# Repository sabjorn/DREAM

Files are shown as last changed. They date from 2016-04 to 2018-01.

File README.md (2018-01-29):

## D.R.E.A.M - *D*ata *R*ules *E*verything *A*round *M*e

## About
*dreamIO* is an ESP8266 based development board for designing interactive art applications. 

The board features MPU-6050 6-Axis IMU, TPS61200 Voltage Regulator, MCP73831 Lipo Charger, and 12x WS2812B RGB LEDs. 

The functionality of the board is made available through an OSC based API. Through this network interface, large, complex, and distributed interactive applications can be developed with little (to no) microcontroller programming. Instead, designers can use any language of their choice (any languague which supports UDP messaging) and any platform of their choice (Mac, Windows, Linux) to write the software which communicates with these devices. 

## Development Status
Early development stages, version 0.~

**Note**: The current PCB design in the git is broken from an attempt to fix 

### Arduino SDK info
Currently only version **2.0.0** of ESP8266 for Arduino is supported for this project. 

## External Libraries
* [ESP8266 Arduino](https://github.com/esp8266/Arduino) - 2.0.0
* [I2CDev](https://github.com/jrowberg/i2cdevlib) for the MPU-6050
* [OSC](https://github.com/CNMAT/OSC) 
* [Adafruit NeoPixels](https://github.com/adafruit/Adafruit_NeoPixel) - 1.0.6 **Use the Arduino Package Manager version**

## Future
The addition of a haptics motor is likely.

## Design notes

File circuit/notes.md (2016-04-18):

All resistors are size `SMD 0603`. They have a maximum dissipation of .1W and none of the resistors will get near this.

based on: http://electronics.stackexchange.com/questions/12409/choosing-surface-mount-resistor-capacitors

The battery is 5cm x 3cm

PCB will (currently) be 6x6mm, 5mm will not work, there is simply not enough space?

#### [Seeed Studio Design Rules](http://support.seeedstudio.com/knowledgebase/articles/422482-fusion-pcb-order-submission-guidelines)

| Item | Specs | |
|---|---|---|
| | Unit: mm | Unit: mil |
| Available Board Thickness | 0.4(4 layer except),0.6, 0.8, 1.0, 1.2, 1.6, 2.0 | 15.7(4 layer except), 23.6, 31.5, 39.4, 47.2, 63.0, 78.7 |
| Board Dimension | min size: 20*20Max size:300*300 | —— |
| Board Thickness Tolerance | ± 10% | ± 10% |
| Dielectric Separation thickness | 0.075 - 5.0 | 2.95 - 196.85 |
| Minimum trace width | 0.1524 | 6 |
| Minimum inner trace width (for 4 layer) | 0.204 | 8 |
| Minimum trace/vias/pads space | 0.1524 | 6 |
| Minimum inner trace/vias/pads space (for 4 layer) | 0.254 | 10 |
| Minimum silkscreen width | 0.1524 | 6 |
| Minimum silkscreen text size | 1 | 40 |
| Minimum distance between pads and silkscreen | 0.178 | 7 |
| Out Layer Copper Thickness (4 layers) | 0.035-0.07(1oz-2oz) | 1.38-2.76 |
| Inner Layer Copper Thickness (4 layers) | 0.017(0.5oz) | 0.67 |
| Drilling Hole Diameter (Mechanical) | 0.3 - 6.35 | 11.81 - 250.00 |
| Annular Ring | ≥0.1524 | ≥6 |
| Diameter Tolerance (Mechanical) | ±0.08 | ± 3.148 |
| SMT min Solder Mask Width | 0.1 | 3.94 |
| Min Solder Mask Clearance | 0.13 | 5.12 |
| Circuit to edge | ≥0.4 | ≥15.76 |
| Mimimum distance between inner line/copper and drilling hole | ≥0.3 | ≥11.82 |
| Minimum milling slot | 1*2 | 39.385*78.77 |
| Slot Tolerance(Mechanical) | ±0.15mm | |
| The minimum board dimension of V-CUT | 80mm*80mm | |
| Aspect Ratio | 08:01:00 | |
| Solder Mask Type | Photosensitive ink | |

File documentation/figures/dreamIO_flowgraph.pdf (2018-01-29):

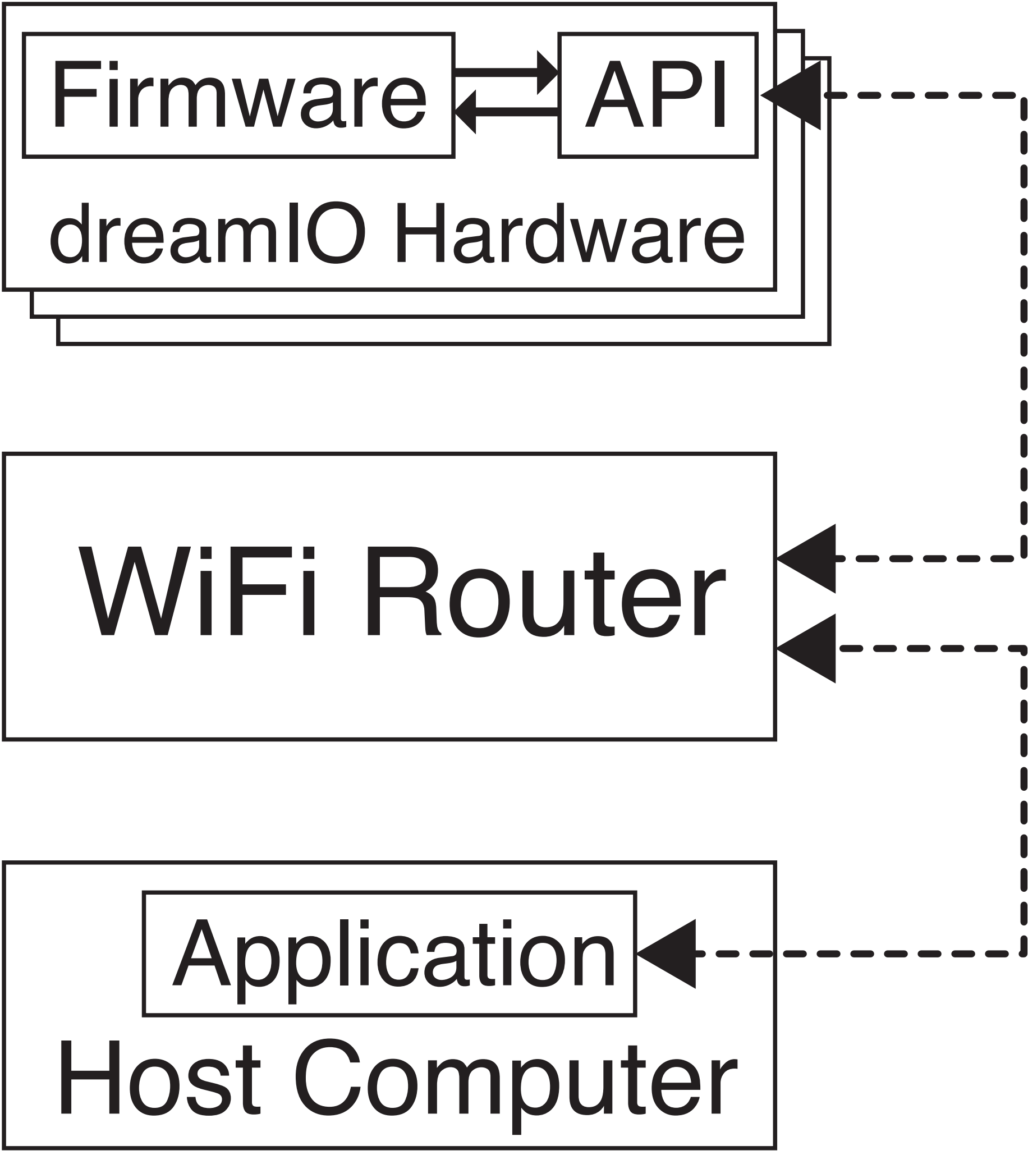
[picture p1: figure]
Application Host Computer; WiFi Router; Firmware; API; dreamIO Hardware

OSC OSC

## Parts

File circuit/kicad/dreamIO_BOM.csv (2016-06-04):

Id | Designator | Package | Quantity | Designation | Supplier and ref
1 | C1,C2 | 0603 | 2 | 4.7uF
2 | C3,C13 | 0603 | 2 | 10uF
3 | C5 | 0603 | 1 | 22uF
4 | C6,C9,C10,C11,C12,C14,C15,C16,C17,C18,C19,C20,C21,C22,C24,C25 | 0603 | 16 | 0.1uF
5 | C23 | 0603 | 1 | 0.01uF
6 | C26 | 0603 | 1 | 2200pF
7 | IC1 | tps61200_QFN-10_PAD | 1 | TPS61200
8 | L1 | 1206E | 1 | 2.2uH, 1.2A
9 | LED1,LED2,LED3,LED4,LED5,LED6,LED7,LED8,LED9,LED10,LED11,LED12 | WS2812B_LED | 12 | WS2812B
10 | P1 | Pin_Header_Straight_1x02 | 1 | BATT
11 | P9 | Pin_Header_Straight_1x03 | 1 | PixelOut
12 | R1 | 0603 | 1 | 330
13 | R2 | 0603 | 1 | 2.0k
14 | R3,R5 | 0603 | 2 | 2M
15 | R4 | 0603 | 1 | 1.2M
16 | R6,R7 | 0603 | 2 | 220k
17 | R8,R9,R10,R11,R16,R13,R14 | 0603 | 7 | 10k
18 | R12 | 0603 | 1 | 220
19 | R25,R26,R27 | 0603 | 3 | 4.7k
20 | U1 | SOT23-5 | 1 | MCP73831
21 | U2 | MICRO-B_USB | 1 | MICRO-B_USB
22 | U4 | ESP-12E | 1 | ESP-12E
23 | D1 | 0603 | 1 | LED
24 | P2,P3 | _Pin2mm_8 | 2 | CONN_01X08
25 | P5 | _Pin2mm_6 | 1 | CONN_01X06
26 | P4 | _Solder_Pad2.54_2 | 1 | CONN_01X02
27 | SW2 | SW_06_SMD | 1 | RESET
28 | SW3 | SW_06_SMD | 1 | PRGM
29 | H4,H4,H4,H4 | 1pin | 4 | SCREWHOLE
30 | SW1 | DPST_TE_SSJ12R04 | 1 | SPDT
31 | SW4 | SW_06_SMD | 1 | HCI2
32 | SW5 | SW_06_SMD | 1 | HCI1
33 | U17 | QFN-24-4x4-EP_steevedit | 1 | MPU-6050
34 | R15 | 0603 | 1 | 330K

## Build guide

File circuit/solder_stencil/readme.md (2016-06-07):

these files are for creating a solder-paste stencil
using a laser cutter an mylar.

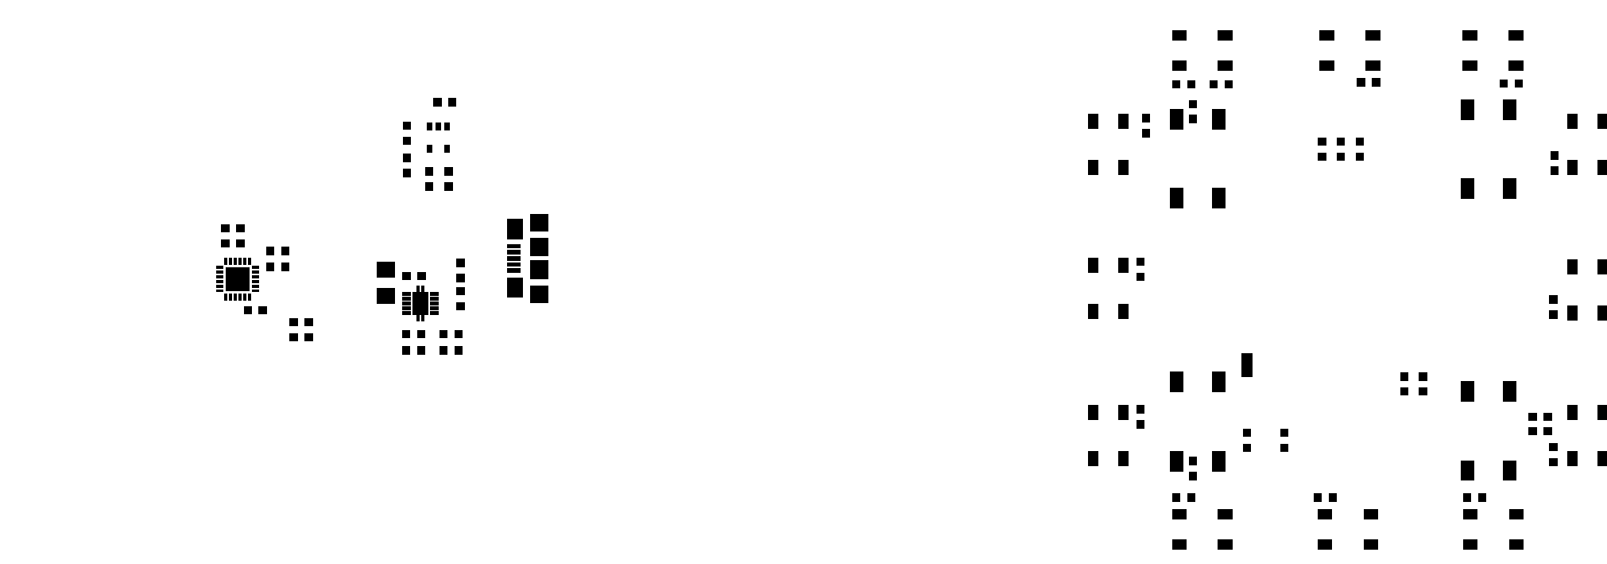
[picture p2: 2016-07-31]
circuit/solder_stencil/stencil_noholes.BMP

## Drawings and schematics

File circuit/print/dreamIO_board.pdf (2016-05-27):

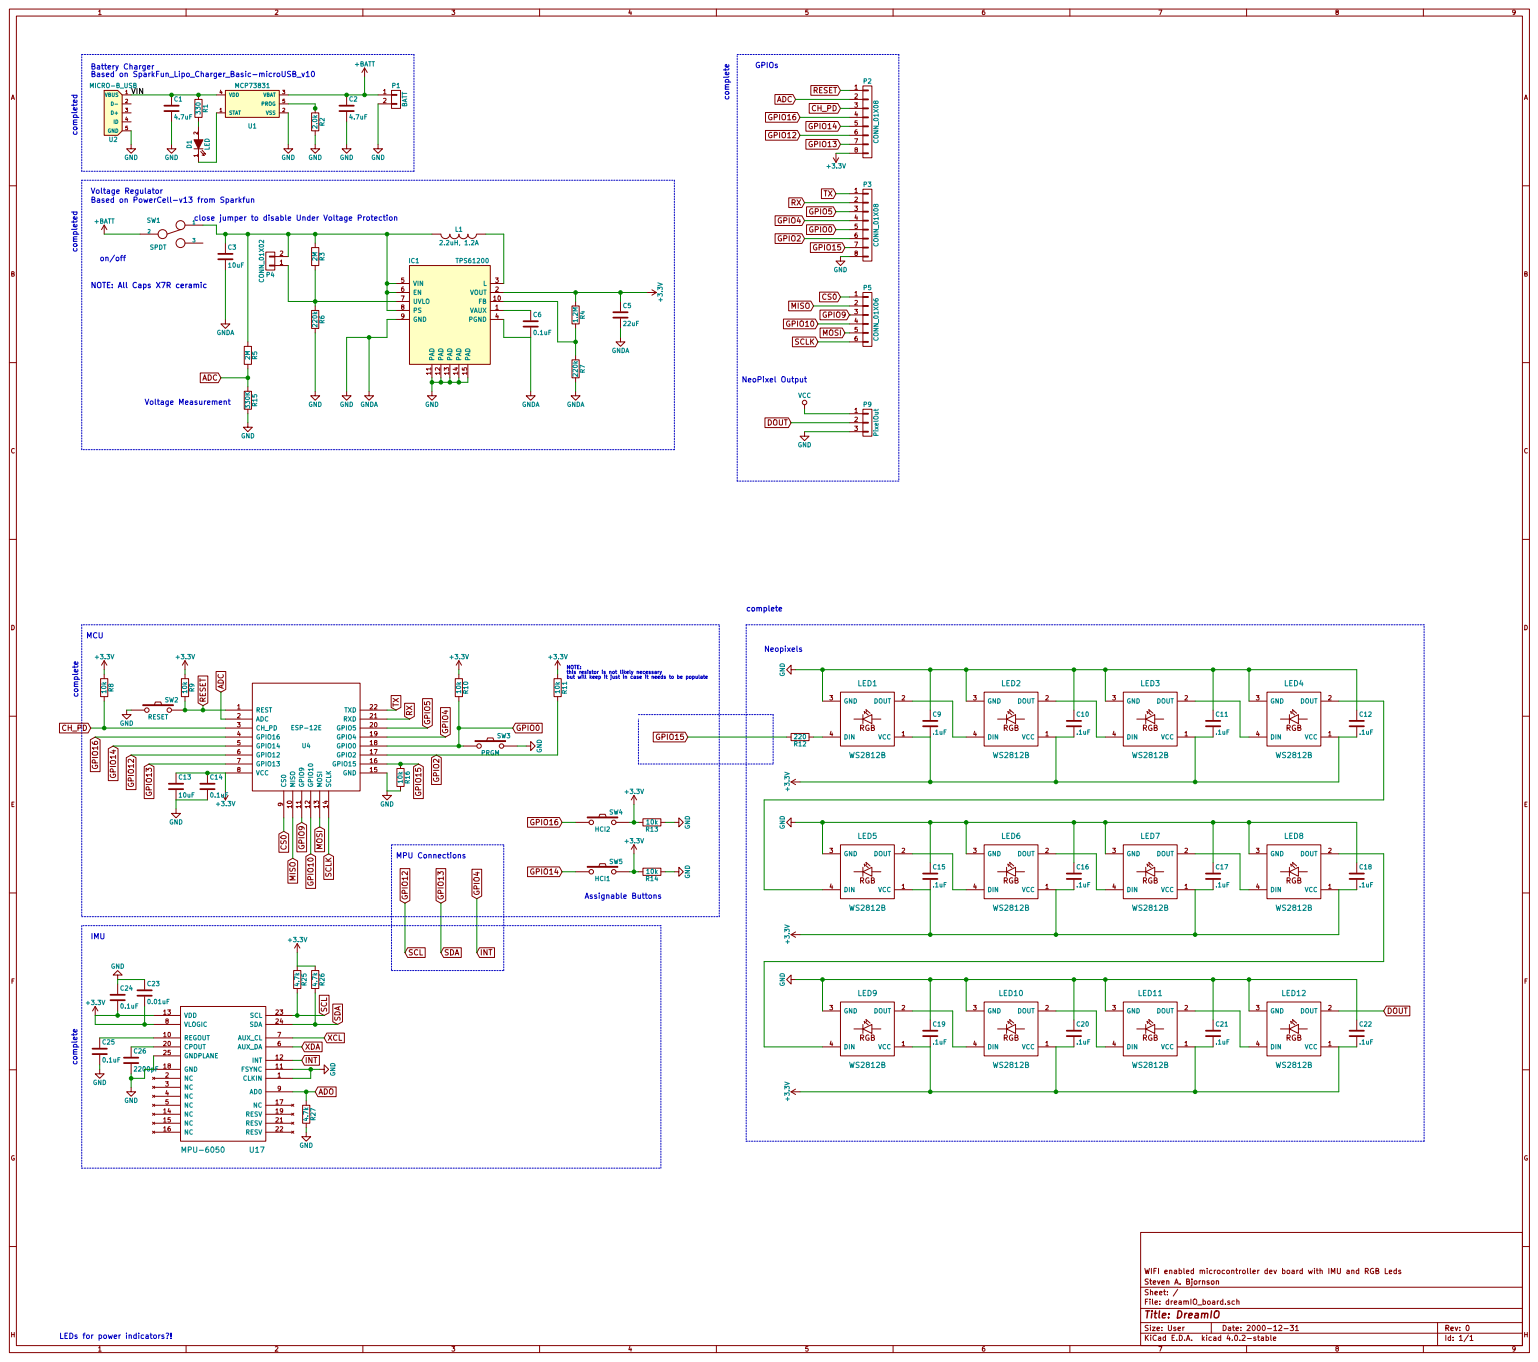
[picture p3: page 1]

1 2 D1 LED Battery Charger Based on SparkFun_Lipo_Charger_Basic-microUSB_v10

close jumper to disable Under Voltage Protection Based on PowerCell-v13 from Sparkfun Voltage Regulator on/off completed completed

this resistor is not likely necessary but will keep it just in case it needs to be populate GPIO13 GPIO12 GPIO14 GPIO16 MCU

9 MISO 10 GPIO5 20 GPIO9 11 RXD 21 GPIO10 12 TXD 22 MOSI 13 SCLK 14 GND 15 GPIO15 16 GPIO2 17 GPIO0 18 GPIO4 19 U4 ESP-12E complete

File: dreamIO_board.sch Sheet: / Steven A. Bjornson WIFI enabled microcontroller dev board with IMU and RGB Leds

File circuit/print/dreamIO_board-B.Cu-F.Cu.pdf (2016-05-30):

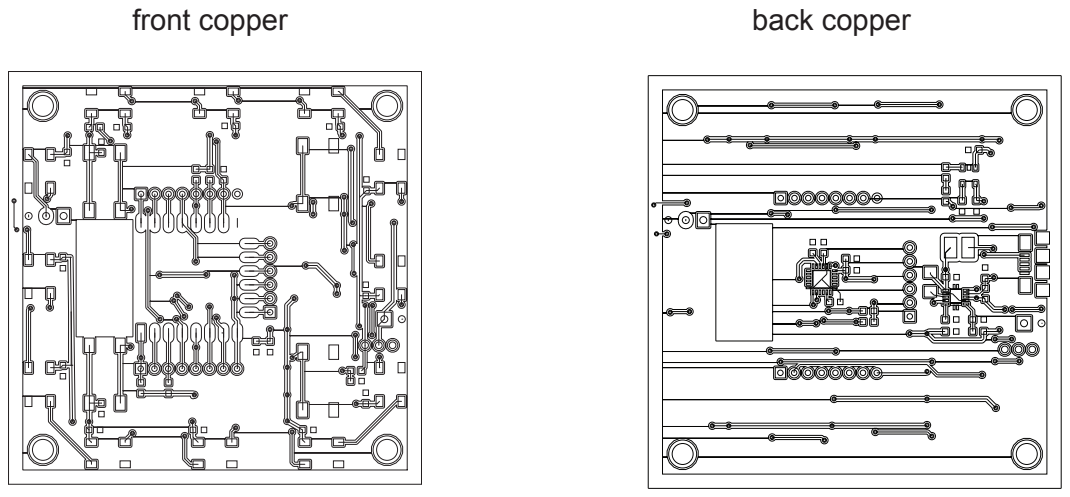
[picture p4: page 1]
front copper; back copper

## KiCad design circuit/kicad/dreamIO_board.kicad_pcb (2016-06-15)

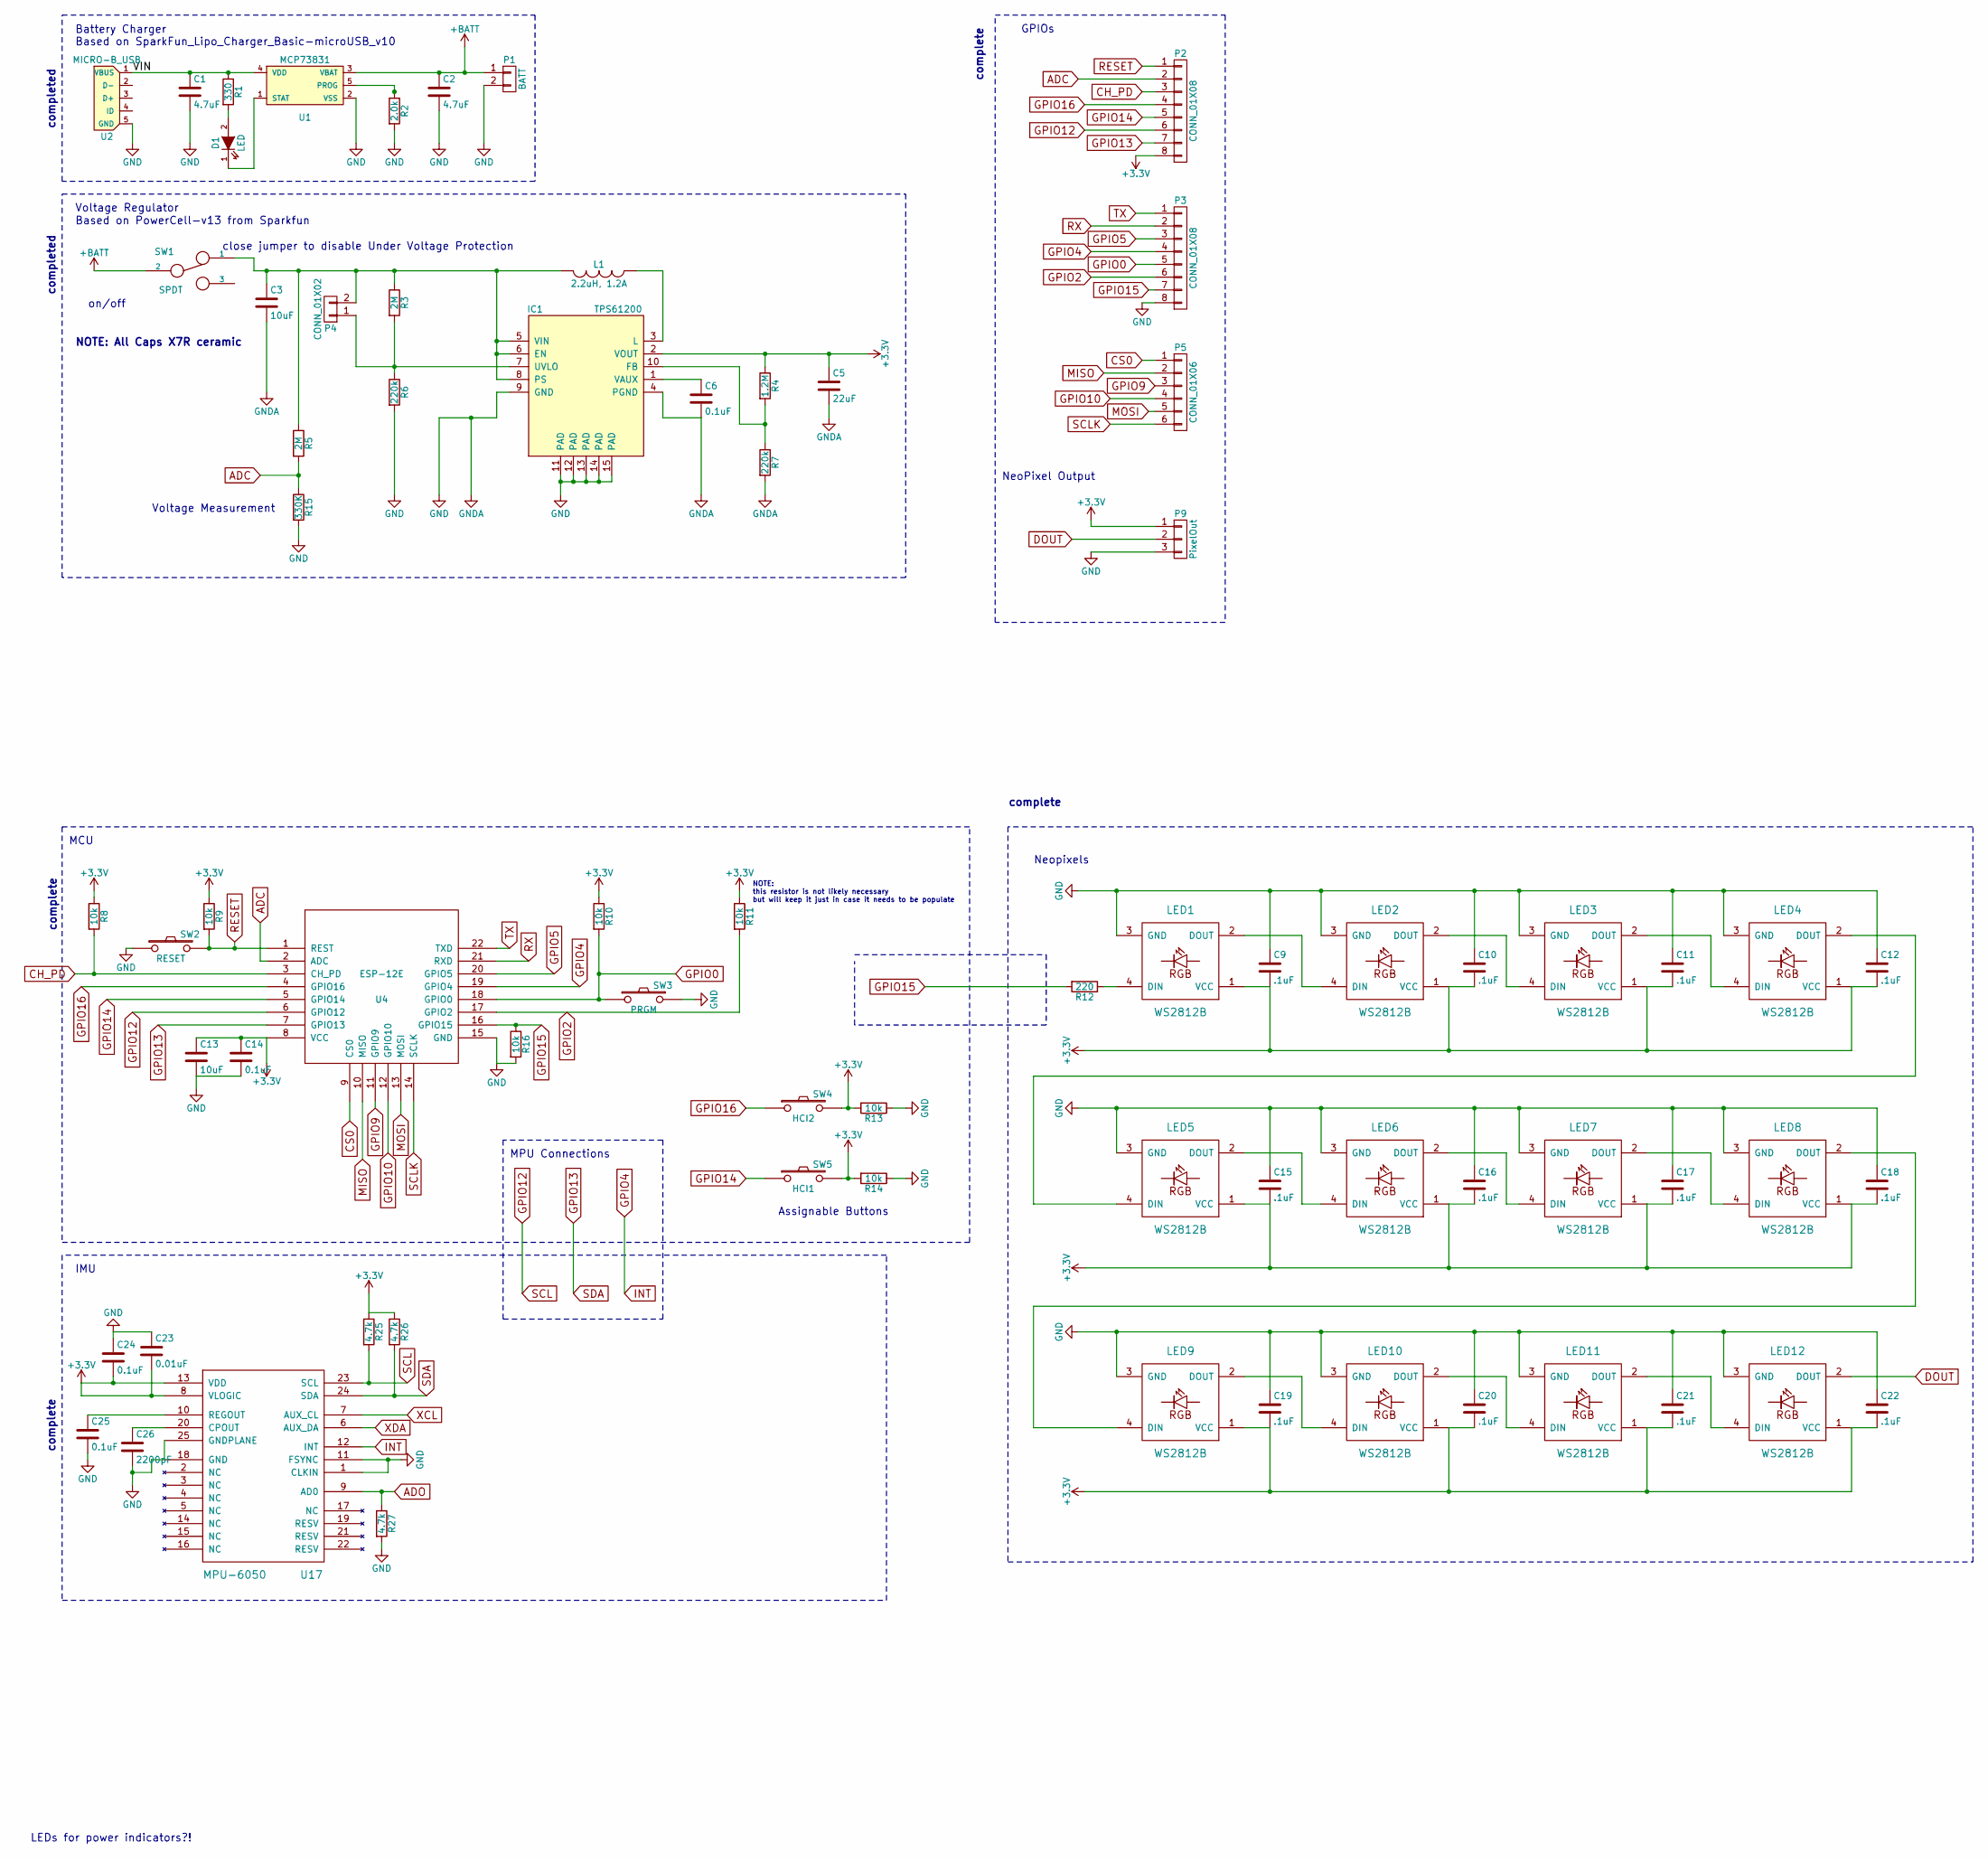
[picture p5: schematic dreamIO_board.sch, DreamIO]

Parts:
C1, C2: 4.7uF; 0603
C3, C13: 10uF; 0603
C5: 22uF; 0603
C6, C14, C24, C25: 0.1uF; 0603
C9, C10, C11, C12, C15, C16, C17, C18, C19, C20, C21, C22: .1uF; 0603
C23: 0.01uF; 0603
C26: 2200pF; 0603
D1: LED; 0603
IC1: TPS61200; tps61200_QFN-10_PAD
L1: 2.2uH, 1.2A; 1206E
LED1, LED2, LED3, LED4, LED5, LED6, LED7, LED8, LED9, LED10, LED11, LED12: WS2812B; WS2812B_LED
P1: BATT; Pin_Header_Straight_1x02
P2, P3: CONN_01X08; _Pin2mm_8
P4: CONN_01X02; _Solder_Pad2.54_2
P5: CONN_01X06; _Pin2mm_6
P9: PixelOut; PIN_ARRAY_3X1
R1: 330; 0603
R2: 2.0k; 0603
R3, R5: 2M; 0603
R4: 1.2M; 0603
R6, R7: 220k; 0603
R8, R9, R10, R11, R13, R14, R16: 10k; 0603
R12: 220; 0603
R15: 330K; 0603
R25, R26, R27: 4.7k; 0603
SW1: SPDT; DPST_TE_SSJ12R04
SW2: RESET; SW_06_SMD
SW3: PRGM; SW_06_SMD
SW4: HCI2; SW_06_SMD
SW5: HCI1; SW_06_SMD
U1: MCP73831; SOT23-5
U2: MICRO-B_USB
U4: ESP-12E
U17: MPU-6050; QFN-24-4x4-EP_steevedit

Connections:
+3V3: C5.1, C9.2, C10.2, C11.2, C12.2, C13.1, C14.1, C15.2, C16.2, C17.2, C18.2, C19.2, C20.2, C21.2, C22.2, C23.2, C24.2, IC1.2 (VOUT), LED1.1 (VCC), LED2.1 (VCC), LED3.1 (VCC), LED4.1 (VCC), LED5.1 (VCC), LED6.1 (VCC), LED7.1 (VCC), LED8.1 (VCC), LED9.1 (VCC), LED10.1 (VCC), LED11.1 (VCC), LED12.1 (VCC), P2.8, P9.1, R4.1, R8.1, R9.1, R10.1, R11.1, R13.2, R14.2, R25.1, R26.1, SW4.2, SW5.2, U4.8 (VCC), U17.8 (VLOGIC), U17.13 (VDD)
+BATT: C2.1, P1.1, SW1.2, U1.3 (VBAT)
/VIN: C1.1, R1.1, U1.4 (VDD), U2.1 (VBUS)
ADC: P2.2, R5.2, R15.1, U4.2 (ADC)
ADO: R27.1, U17.9 (AD0)
CH_PD: P2.3, R8.2, U4.3 (CH_PD)
CS0: P5.1, U4.9 (CS0)
DOUT: LED12.2 (DOUT), P9.2
GND: C1.2, C2.2, C3.2, C5.2, C6.2, C9.1, C10.1, C11.1, C12.1, C13.2, C14.2, C15.1, C16.1, C17.1, C18.1, C19.1, C20.1, C21.1, C22.1, C23.1, C24.1, C25.2, C26.2, IC1.4 (PGND), IC1.9 (GND), IC1.11 (PAD), IC1.12 (PAD), IC1.13 (PAD), IC1.14 (PAD), IC1.15 (PAD), LED1.3 (GND), LED2.3 (GND), LED3.3 (GND), LED4.3 (GND), LED5.3 (GND), LED6.3 (GND), LED7.3 (GND), LED8.3 (GND), LED9.3 (GND), LED10.3 (GND), LED11.3 (GND), LED12.3 (GND), P1.2, P3.8, P9.3, R2.2, R6.2, R7.2, R13.1, R14.1, R15.2, R16.2, R27.2, SW2.1, SW3.2, U1.2 (VSS), U2.5 (GND), U4.15 (GND), U17.1 (CLKIN), U17.11 (FSYNC), U17.18 (GND), U17.25 (GNDPLANE)
GPIO0: P3.5, R10.2, SW3.1, U4.18 (GPIO0)
GPIO2: P3.6, R11.2, U4.17 (GPIO2)
GPIO4: P3.4, U4.19 (GPIO4), U17.12 (INT)
GPIO5: P3.3, U4.20 (GPIO5)
GPIO9: P5.3, U4.11 (GPIO9)
GPIO10: P5.4, U4.12 (GPIO10)
GPIO12: P2.6, R25.2, U4.6 (GPIO12), U17.23 (SCL)
GPIO13: P2.7, R26.2, U4.7 (GPIO13), U17.24 (SDA)
GPIO14: P2.5, SW5.1, U4.5 (GPIO14)
GPIO15: P3.7, R12.2, R16.1, U4.16 (GPIO15)
GPIO16: P2.4, SW4.1, U4.4 (GPIO16)
MISO: P5.2, U4.10 (MISO)
MOSI: P5.5, U4.13 (MOSI)
unnamed: C3.1, IC1.5 (VIN), IC1.6 (EN), IC1.8 (PS), L1.2, P4.2, R3.1, R5.1, SW1.1
unnamed: C6.1, IC1.1 (VAUX)
unnamed: C25.1, U17.10 (REGOUT)
unnamed: C26.1, U17.20 (CPOUT)
unnamed: D1.1 (K), U1.1 (STAT)
unnamed: D1.2 (A), R1.2
unnamed: IC1.3 (L), L1.1
unnamed: IC1.7 (UVLO), P4.1, R3.2, R6.1
unnamed: IC1.10 (FB), R4.2, R7.1
unnamed: LED1.2 (DOUT), LED2.4 (DIN)
unnamed: LED1.4 (DIN), R12.1
unnamed: LED2.2 (DOUT), LED3.4 (DIN)
unnamed: LED3.2 (DOUT), LED4.4 (DIN)
unnamed: LED4.2 (DOUT), LED5.4 (DIN)
unnamed: LED5.2 (DOUT), LED6.4 (DIN)
unnamed: LED6.2 (DOUT), LED7.4 (DIN)
unnamed: LED7.2 (DOUT), LED8.4 (DIN)
unnamed: LED8.2 (DOUT), LED9.4 (DIN)
unnamed: LED10.2 (DOUT), LED11.4 (DIN)
unnamed: LED9.2 (DOUT), LED10.4 (DIN)
unnamed: LED11.2 (DOUT), LED12.4 (DIN)
unnamed: R2.1, U1.5 (PROG)
RESET: P2.1, R9.2, SW2.2, U4.1 (REST)
RX: P3.2, U4.21 (RXD)
SCLK: P5.6, U4.14 (SCLK)
TX: P3.1, U4.22 (TXD)

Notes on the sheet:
Battery Charger Based on SparkFun_Lipo_Charger_Basic-microUSB_v10
close jumper to disable Under Voltage Protection
Based on PowerCell-v13 from Sparkfun
Voltage Regulator
on/off
completed
NOTE: All Caps X7R ceramic
Neopixels
IMU
complete
NOTE: this resistor is not likely necessary but will keep it just in case it needs to be populate
MCU
GPIOs
LEDs for power indicators?!
MPU Connections
NeoPixel Output
Assignable Buttons
Voltage Measurement

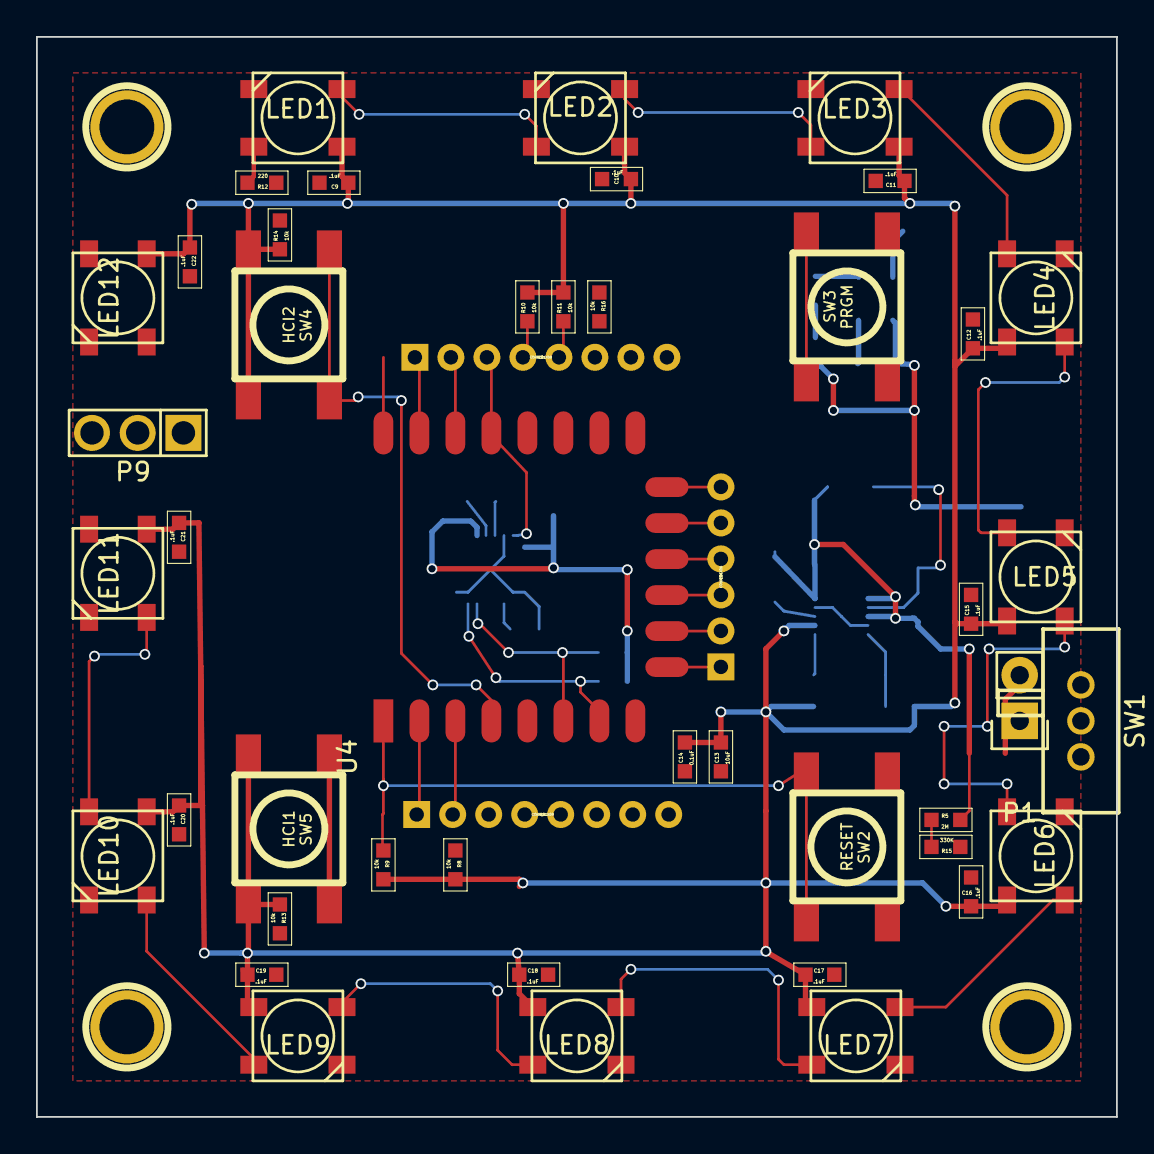
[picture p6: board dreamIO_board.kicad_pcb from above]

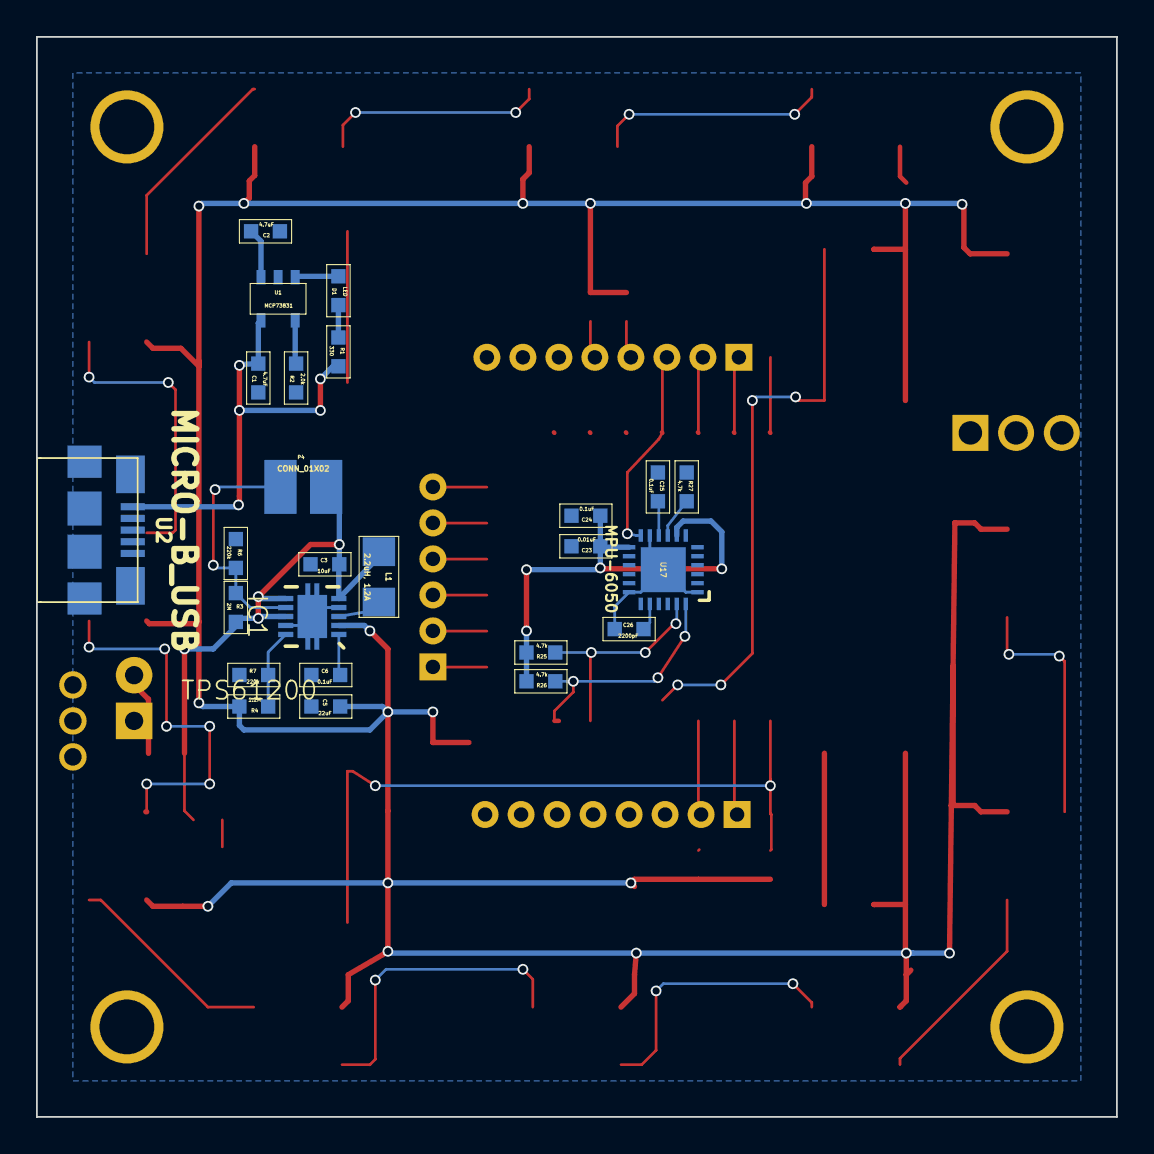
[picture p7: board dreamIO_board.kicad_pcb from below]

Board: 2 copper layers, 60.0 x 60.0 mm, 76 parts (25 on the bottom side), 48 nets.

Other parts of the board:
H4, H4#2, H4#3, H4#4: SCREWHOLE; 1pin

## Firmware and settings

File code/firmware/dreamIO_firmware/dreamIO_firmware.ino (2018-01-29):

/*Example code for OSC message send/recieve with ESP8266
Based on example code made available through CNMAT
Written by: Steven A. Bjornson | 19/12/15

Included is a Max/MSP patch for controlling a single LED on board.
Max patch uses CNMAT OSC externals*/
#include <ESP8266WiFi.h>
#include <ESP8266WiFiMulti.h>
// #include <WiFiClient.h>
// #include <WiFiClientSecure.h>
#include <WiFiServer.h>
#include <WiFiUdp.h>
#include <ESP8266mDNS.h>
#include <ArduinoOTA.h>

#include <OSCMessage.h>
#include <OSCBundle.h>

#include <Adafruit_NeoPixel.h>
#include "wifiCred.h" //used to store SSID and PASS

#include <Math.h>
#include <cstdint>

#include "MotionState.h"
#include "ImuDataContainer.h"

/*Voltage Measurement*/
// Voltage divider on ADC allows for a measurement of battery voltage.
// maybe these don't need to be preprocessor
#define V_RES float(1./256.) //the number of volts per step
#define R1 float(200.)
#define R2 float(33.)
#define V_SCALE float(R2 / (R1 + R2))
#define V_MIN float(2.6) //the undervoltage shutoff of voltage regulator
#define V_MAX float(4.2) //the theoretical maximum voltage of LiPo
#define SCALED_V_MIN float(V_SCALE * V_MIN / V_RES)
#define SCALED_V_MAX float(V_SCALE * V_MAX / V_RES)

#define abs(x) ((x)>0?(x):-(x)) //taken from STD

/*MPU*/
#include "I2Cdev.h"
#include "MPU6050_6Axis_MotionApps20.h"

#if I2CDEV_IMPLEMENTATION == I2CDEV_ARDUINO_WIRE
    #include "Wire.h"
#endif

MPU6050 mpu;

// MPU control/status vars
bool dmpReady = false;  // set true if DMP init was successful
uint8_t mpuIntStatus;   // holds actual interrupt status byte from MPU
uint8_t devStatus;      // return status after each device operation (0 = success, !0 = error)
uint16_t packetSize;    // expected DMP packet size (default is 42 bytes)
uint16_t fifoCount;     // count of all bytes currently in FIFO
uint8_t fifoBuffer[64]; // FIFO storage buffer

// orientation/motion vars
Quaternion q;           // [w, x, y, z]         quaternion container
VectorInt16 aa;         // [x, y, z]            accel sensor measurements
VectorInt16 aaReal;     // [x, y, z]            gravity-free accel sensor measurements
VectorInt16 aaWorld;    // [x, y, z]            world-frame accel sensor measurements
VectorFloat gravity;    // [x, y, z]            gravity vector
VectorInt16 gyro;
float euler[3];         // [psi, theta, phi]    Euler angle container
float ypr[3];           // [yaw, pitch, roll]   yaw/pitch/roll container and gravity vector

IMUData mpu_data; //replaces the above

float gyrothresh = 0.003; //trigger for checking for activity
float accelthresh = 0.095; //trigger for checking for activity

#define sensitivity float(2000) //the curent sensativity of the gyroscop
//===========================================================================//

/*Internal Representation Object*/
MotionState self;

//MPU soft-wire
#define SDA_PIN 13
#define SCL_PIN 12

/*Neopixels*/
#define PIX_PIN 15
#define NUMPIX 12
Adafruit_NeoPixel strip = Adafruit_NeoPixel(NUMPIX, PIX_PIN, NEO_GRB + NEO_KHZ800);
//===========================================================================//

int status = 0;     // the Wifi radio's status

IPAddress outIp(255, 255, 255, 255); //broadcast UDP
//===========================================================================//

/*UDP*/
WiFiUDP Udp; //make ESP8266 Udp instance
const unsigned int inPort = 8888;
const unsigned int outPort = 9999;
//===========================================================================//

/*UDP Scheduler*/
bool transmit_flag = 1;
long old_time, current_time = 0;
long schedule_time = 25; //interval between UDP sends *NEEDED! Will crash otherwise
uint8_t old_val = 0;
//===========================================================================//

/*OTA*/
int prog = 0; //keeps track of download prograss for OTA to be displayed on WS2812s
//===========================================================================//

/*Packet Counter*/
// countes every time a UDP packet is sent
uint64_t pack_count = 0;
//===========================================================================//

/*Interrupt Detection Routine*/
volatile bool mpuInterrupt = false;     // indicates whether MPU interrupt pin has gone high
void dmpDataReady() {
    mpuInterrupt = true;
}
//===========================================================================//

/*OSC Callbacks*/

//Neopixel Control Callback
void leds(OSCMessage &msg)
{
  uint8_t n, r, g, b = 0;
  
  // change the colour of ALL pixelsels simultaneously
  if(msg.size() < 4)
  {
    if (msg.isInt(0))
      r = msg.getInt(0);
    if (msg.isInt(1))
      g = msg.getInt(1);
    if (msg.isInt(2))
      b = msg.getInt(2);
    
    for (uint16_t i = 0; i < NUMPIX; i++)
      strip.setPixelColor(i, r, g, b);
  }

  // change the colour of pixel 'n'.
  else
  {
    if (msg.isInt(0))
      n = msg.getInt(0);
    if (msg.isInt(1))
      r = msg.getInt(1);
    if (msg.isInt(2))
      g = msg.getInt(2);
    if (msg.isInt(3))
      b = msg.getInt(3);

    strip.setPixelColor(n, r, g, b);
  }
  strip.show();
}

// hsl endpoint
void hsl(OSCMessage &msg){
  uint16_t rgb[3];

  hslToRgb(msg.getFloat(0), msg.getFloat(1), msg.getFloat(2), rgb);
  for (uint16_t i = 0; i < NUMPIX; i++)
      strip.setPixelColor(i, rgb[0], rgb[1], rgb[2]);
  strip.show();
}

void brightness(OSCMessage &msg)
{
  int temp = 0;
  if (msg.isInt(0)){
    if (msg.getInt(0) < 0)
      temp = 0;
    else if (msg.getInt(0) > 255)
      temp = 255;
    else
      temp = msg.getInt(0);
  }
  else if(msg.isFloat(0)){
    if (msg.getFloat(0) < 0)
      temp = 0;
    else if (msg.getFloat(0) > 1.)
      temp = 255;
    else
      temp = msg.getFloat(0) * 255;
  }

  strip.setBrightness(temp);
  strip.show();
}

//change schedule_time
void update_interval(OSCMessage &msg)
{
  if(msg.isInt(0))
    schedule_time = long(msg.getInt(0));
  if(msg.isFloat(0))
    schedule_time = long(msg.getFloat(0));

  transmit_flag = 1;
  if (schedule_time == 0)
    transmit_flag = 0;
  else if (schedule_time < 10)
    schedule_time = 10;
}

//callback to restart ESP
void reset(OSCMessage &msg)
{
  ESP.reset();
}

void accelThresh(OSCMessage &msg){
  if(msg.isFloat(0))
    self.setAccelThresh(msg.getFloat(0));
}

void gyroThresh(OSCMessage &msg){
  if(msg.isFloat(0))
    self.setGyroThresh(msg.getFloat(0));
}

void motionDecay(OSCMessage &msg){
  int temp = 0;
  if(msg.isInt(0))
    temp = msg.getInt(0);
  else if(msg.isFloat(0))
    temp = int(msg.getFloat(0));

  self.setMotionDecay(temp);
}
//===========================================================================//

void hslToRgb(double h, double sl, double l, uint16_t *rgb)
{
      double v;
      double r,g,b;

      if (h == 1.)
        h = 0.;

      r = l;   // default to grey
      g = l;
      b = l;
      v = (l <= 0.5) ? (l * (1.0 + sl)) : (l + sl - l * sl);
      if (v > 0)
      {
            double m;
            double sv;
            int sextant;
            double fract, vsf, mid1, mid2;

            m = l + l - v;
            sv = (v - m ) / v;
            h *= 6.0;
            sextant = (int)h;
            fract = h - sextant;
            vsf = v * sv * fract;
            mid1 = m + vsf;
            mid2 = v - vsf;
            switch (sextant)
            {
                  case 0:
                        r = v;
                        g = mid1;
                        b = m;
                        break;
                  case 1:
                        r = mid2;
                        g = v;
                        b = m;
                        break;
                  case 2:
                        r = m;
                        g = v;
                        b = mid1;
                        break;
                  case 3:
                        r = m;
                        g = mid2;
                        b = v;
                        break;
                  case 4:
                        r = mid1;
                        g = m;
                        b = v;
                        break;
                  case 5:
                        r = v;
                        g = m;
                        b = mid2;
                        break;
            }
      }
      rgb[0] = r * 255.0f;
      rgb[1] = g * 255.0f;
      rgb[2] = b * 255.0f;
}

void setup() {
  self.initialize(&mpu_data, accelthresh, gyrothresh, 500); //initialize physical state representation

  //Initialize serial and wait for port to open:
  Serial.begin(115200); 
  while (!Serial) {
    ; // wait for serial port to connect. Needed for Leonardo only
  }
  //=========================================================================//

  /*Neopixels*/
  strip.begin();
  strip.show(); // Initialize all pixels to 'off'
  //=========================================================================//

  /* join I2C bus */
  //(I2Cdev library doesn't do this automatically)
  #if I2CDEV_IMPLEMENTATION == I2CDEV_ARDUINO_WIRE
      Wire.begin(SDA_PIN, SCL_PIN);
      int TWBR = 24; // 400kHz I2C clock (200kHz if CPU is 8MHz). Comment this line if having compilation difficulties with TWBR.
  #elif I2CDEV_IMPLEMENTATION == I2CDEV_BUILTIN_FASTWIRE
      Fastwire::setup(400, true);
  #endif
  //=========================================================================//

  /*MPU6050*/
  mpu.initialize();
  devStatus = mpu.dmpInitialize();

  // supply your own gyro offsets here, scaled for min sensitivity
  mpu.setXGyroOffset(220);
  mpu.setYGyroOffset(76);
  mpu.setZGyroOffset(-85);
  mpu.setZAccelOffset(1788); // 1688 factory default for my test chip

  // make sure it worked (returns 0 if so)
  if (devStatus == 0) {
      // turn on the DMP, now that it's ready
      //Serial.println(F("Enabling DMP..."));
      mpu.setDMPEnabled(true);

      // enable Arduino interrupt detection
      //Serial.println(F("Enabling interrupt detection (Arduino external interrupt 0)..."));
      attachInterrupt(4, dmpDataReady, RISING);
      mpuIntStatus = mpu.getIntStatus();

      // set our DMP Ready flag so the main loop() function knows it's okay to use it
      //Serial.println(F("DMP ready! Waiting for first interrupt..."));
      dmpReady = true;

      // get expected DMP packet size for later comparison
      packetSize = mpu.dmpGetFIFOPacketSize();
  } else {
      // ERROR!
      // 1 = initial memory load failed
      // 2 = DMP configuration updates failed
      // (if it's going to break, usually the code will be 1)
      // Serial.print(F("DMP Initialization failed (code "));
      // Serial.print(devStatus);
      // Serial.println(F(")"));
  }
  //===========================================================================//
  
  uint8_t wifi_loading = 0;

  // attempt to connect to Wifi network:
  while ( status != WL_CONNECTED) 
  { 
    Serial.print("Attempting to connect to WPA SSID: ");
    Serial.println(SSID);
    
    // Connect to WPA/WPA2 network: 
    WiFi.mode(WIFI_STA);   
    status = WiFi.begin(SSID, PASS);
    
    //LEDs cycle through R/G/B while connecting
    for (uint16_t i = 0; i < NUMPIX; ++i)
    {
      switch(wifi_loading % 3){
        case 0:
          strip.setPixelColor(i, 255, 0, 0);
          break;
        case 1:
          strip.setPixelColor(i, 0, 255, 0);
          break;
        case 2:
          strip.setPixelColor(i, 0, 0, 255);
          break;
      }
    }
    strip.show();
    wifi_loading++;


    // wait 1 seconds for connection:
    delay(1000);
  }
  
  //clear
  for (uint16_t i = 0; i < NUMPIX; i++)
    strip.setPixelColor(i, 0);
  strip.show();

  // you're connected now, so print out the data:
  // Serial.println("You're connected to the network");
  // Serial.print("IP address: ");
  // Serial.println(WiFi.localIP());
  //=========================================================================//

  /*Setup OSC*/
  Udp.begin(inPort); //input Udp stream

  /*Over the Air Updates*/  
  //Progress Bar
  ArduinoOTA.onStart([]() {
    Serial.println("Start");
  });

  ArduinoOTA.onEnd([]() {
    Serial.println("End");

    //LEDs turn blue when update complete
    for (uint16_t i = 0; i < NUMPIX; i++)
      strip.setPixelColor(i, 0, 0, 255);
    strip.show();
  });

  ArduinoOTA.onProgress([](unsigned int progress, unsigned int total) {
    Serial.printf("Progress: %u%%\n", (progress / (total / 100)));

    if (prog != progress/float(total) * (NUMPIX+1))
    {
      for (uint16_t i = 0; i < NUMPIX; ++i)
      {
        if(i < prog)
          strip.setPixelColor(i, 0, 255, 0);
        else
          strip.setPixelColor(i, 0);
      }
      strip.show();

      prog = progress/float(total) * NUMPIX;
    }

  });

  ArduinoOTA.onError([](ota_error_t error) {
    Serial.printf("Error[%u]: ", error);
    if (error == OTA_AUTH_ERROR) Serial.println("Auth Failed");
    else if (error == OTA_BEGIN_ERROR) Serial.println("Begin Failed");
    else if (error == OTA_CONNECT_ERROR) Serial.println("Connect Failed");
    else if (error == OTA_RECEIVE_ERROR) Serial.println("Receive Failed");
    else if (error == OTA_END_ERROR) Serial.println("End Failed");

    //LEDs turn red if failed to update
    for (uint16_t i = 0; i < NUMPIX; i++)
      strip.setPixelColor(i, 255, 0, 0);
    strip.show();
  });

  //Start OTA Service
  ArduinoOTA.begin();
  //=========================================================================//

}

void loop() {
  ArduinoOTA.handle(); //check OTA
  
  //if (!dmpReady) return; // if programming failed, don't try to do anything

  /*Scheduler*/
  //possible make object in future  
  current_time = millis(); 
  
  // wait for MPU interrupt or extra packet(s) available
  if (!mpuInterrupt && fifoCount < packetSize && current_time - old_time > schedule_time && transmit_flag) {
    /*OSC Out*/
    //declare a bundle
    OSCBundle bndl;

    //deals with generating the output endpoints automatically (adding ChipID for unique)
    //note: in the future this should be handled better (object or at least function)
    char concat[80];

    sprintf(concat, "/%06x%s", ESP.getChipId(), "/time");
    bndl.add(concat).add((int32_t)millis()); //time since active :: indicates a connection
    
    sprintf(concat, "/%06x%s", ESP.getChipId(), "/ypr");
    bndl.add(concat).add(self.getYPR()[0]).add(self.getYPR()[1]).add(self.getYPR()[2]); //yaw/pitch/roll

    sprintf(concat, "/%06x%s", ESP.getChipId(), "/accel");
    bndl.add(concat).add(self.getAccel()[0]).add(self.getAccel()[1]).add(self.getAccel()[2]); //raw acceleration

    sprintf(concat, "/%06x%s", ESP.getChipId(), "/gyro");
    bndl.add(concat).add(self.getGyro()[2]).add(self.getGyro()[1]).add(self.getGyro()[0]); //raw gyroscope

    sprintf(concat, "/%06x%s", ESP.getChipId(), "/batt");
    bndl.add(concat).add(float((analogRead(A0) >> 2)-SCALED_V_MIN)/(SCALED_V_MAX - SCALED_V_MIN)); //battery voltage [0,1]
    
    sprintf(concat, "/%06x%s", ESP.getChipId(), "/side");
    bndl.add(concat).add(self.whichSide()).add(self.sideValue());

    sprintf(concat, "/%06x%s", ESP.getChipId(), "/motion");
    bndl.add(concat).add((int32_t)self.isMotion());

    sprintf(concat, "/%06x%s", ESP.getChipId(), "/debug");
    bndl.add(concat).add(mpu_data.gravity.x).add(mpu_data.gravity.y).add(mpu_data.gravity.z);

    Udp.beginPacket(outIp, outPort);
    bndl.send(Udp); // send the bytes to the SLIP stream  
    Udp.endPacket(); // mark the end of the OSC Packet
    bndl.empty(); // empty the bundle to free room for a new one
    //=======================================================================//

    pack_count += 1;
    old_time = millis();
  }
  //=========================================================================//
  /*FIX THIS TO ONLY BE BUNDLE?*/
  /*OSC In*/
  #ifdef BUNDLE
    //Bundle example
    OSCBundle OSCin;
  #else
    // single message example
    OSCMessage OSCin;
  #endif
  
  int size;
 
  if( (size = Udp.parsePacket())>0)
  {
    while(size--)
     OSCin.fill(Udp.read());

    if(!OSCin.hasError())
    {
      OSCin.dispatch("/leds", leds);
      OSCin.dispatch("/update", update_interval);
      OSCin.dispatch("/reset", reset);
      OSCin.dispatch("/alpha", brightness);
      OSCin.dispatch("/hsl", hsl);
      OSCin.dispatch("/accelThresh", accelThresh);
      OSCin.dispatch("/gyroThresh", gyroThresh);
      OSCin.dispatch("/motionDecay", motionDecay);

    }
  }
  //=========================================================================//

  /*MPU6050 Processes*/
  mpuInterrupt = false; // reset interrupt flag and get INT_STATUS byte
  mpuIntStatus = mpu.getIntStatus();

  // get current FIFO count
  fifoCount = mpu.getFIFOCount();

  // check for overflow (this should never happen unless our code is too inefficient)
  if ((mpuIntStatus & 0x10) || fifoCount == 1024) {
      // reset so we can continue cleanly
      mpu.resetFIFO();
      //Serial.println(F("FIFO overflow!"));
  } 
  // otherwise, check for DMP data ready interrupt (this should happen frequently)
  else if (mpuIntStatus & 0x02) {
    // wait for correct available data length, should be a VERY short wait
    while (fifoCount < packetSize) fifoCount = mpu.getFIFOCount();

    // read a packet from FIFO
    mpu.getFIFOBytes(fifoBuffer, packetSize);
    
    // track FIFO count here in case there is > 1 packet available
    // (this lets us immediately read more without waiting for an interrupt)
    fifoCount -= packetSize;

    mpu.dmpGetQuaternion(&mpu_data.q, fifoBuffer);
    mpu.dmpGetGravity(&mpu_data.gravity, &mpu_data.q);
    mpu.dmpGetAccel(&mpu_data.aa, fifoBuffer);
    mpu.dmpGetLinearAccel(&mpu_data.aaReal, &mpu_data.aa, &mpu_data.gravity);
    mpu.dmpGetGyro(&mpu_data.gyro, fifoBuffer);
    mpu.dmpGetYawPitchRoll(mpu_data.ypr, &mpu_data.q, &mpu_data.gravity);
    self.update(); //update internal physical representation
  }
  //=========================================================================//
}

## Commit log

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2016-01-06 added a throttle to maxpatch to prevent excessive message speed. Also added example patch for controlling a 3D object with jit.gl
2016-01-07 added an example for a device without an MPU. This device has controllable NeoPixels
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2016-04-03 forgot to add the circuit design to git.
    [_saved_dreamIO_board.sch, dreamIO_board.kicad_pcb, dreamIO_board.sch]
2016-04-04 finished circuit schematic. Needs review
    [_saved_dreamIO_board.sch, dreamIO_board.sch]
2016-04-10 added notes and updated circuit design
    [_saved_dreamIO_board.sch, dreamIO_board.sch]
2016-04-17 added custom footprint for tsp61200 regulator
    [_saved_dreamIO_board.sch, dreamIO_board.kicad_pcb, dreamIO_board.sch]
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2016-04-17 fixed IC1 footprint
    [dreamIO_board.kicad_pcb, dreamIO_board.sch]
2016-04-18 grouped PCB components together for board:
    [dreamIO_board.kicad_pcb, dreamIO_board.sch]
2016-05-09 finished layout
    [dreamIO_board.kicad_pcb, dreamIO_board.sch]
2016-05-16 added human input buttons
    [dreamIO_board.kicad_pcb, dreamIO_board.sch]
2016-05-16 moved the on off switch
    [dreamIO_board.kicad_pcb]
2016-05-16 tried to get leds to work on one of the demo units. for some reason they just are nott working
2016-05-16 fixed the problem with the LEDs on the other board. Turns out the OSCNeoPixelExample had not been updated to the new API (which is present in the max/patch)
2016-05-16 realized the cascaded regulators might not be necessary since the output of the Neopixels at 3.3v is quite bright. While 5V would be brighter, it may not always be necessary to buy the extra parts
    [dreamIO_board.kicad_pcb, dreamIO_board.sch]
2016-05-25 changed pinout for MPU6050 to include groundplane under area. started on routing
    [dreamIO_board.kicad_pcb, dreamIO_board.sch]
2016-05-25 routed some traces. May need to go back in and clean some up.
    [dreamIO_board.kicad_pcb]
2016-05-26 removed the 3.3V regulator. The TPS61200 is now the main regulator and will be 5V.
    [dreamIO_board.kicad_pcb, dreamIO_board.sch]
2016-05-26 added ADC voltage measurement. A voltage resistor of R1 2M and R2 330K keeps the maximum voltage of the battery (4.2V) below the 1V maximum for the analog pin. If the resistor network is not populate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
    [dreamIO_board.kicad_pcb, dreamIO_board.sch]
2016-05-26 changed position of on-off switch, batt connection, and USB input. Realized the USB plug didn`t have to be right in the center of one side
    [dreamIO_board.kicad_pcb]
2016-05-26 laid a few more traces. roughly 78 to go;
    [dreamIO_board.kicad_pcb]
2016-05-26 laid a few more traces. 50~ to go
    [dreamIO_board.kicad_pcb]
2016-05-26 had to add the bak and sch files for the circuit. not sure why they were not added before
    [dreamIO_board.sch]
2016-05-26 removed a (seemingly) extra capacitor from TPS section. Emulated the layout for TPS from datasheet. roughly 40 connections to go. wooooo!
    [dreamIO_board.kicad_pcb, dreamIO_board.sch]
2016-05-27 finished board layout
    [dreamIO_board.kicad_pcb]
2016-05-27 added gerber exports and moved all exports intended to be printed to a new directory
    [dreamIO_board-B.Cu.gbr, dreamIO_board-B.Mask.gbr, dreamIO_board-B.SilkS.gbr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]
2016-05-27 added more print info
    [dreamIO_board.kicad_pcb]
2016-05-30 added BOM
    [dreamIO_BOM.csv]
2016-05-30 changed formatting of BOM csv. replacing the ; with ,
    [dreamIO_BOM.csv]
2016-05-30 fixed svg outputs of PCB for printing
2016-06-04 added laser cutting case file and a large set of different symbols to try
    [dreamIO_BOM.csv]
2016-06-07 created a solder_stencil set for making mylar solder-paste stencils. Also, switched all 2mm headers on PCB to 2.54mm headers. Have not yet finished rerouting from this change
    [dreamIO_board.kicad_pcb]
2016-06-15 fixed error on board: neopixel out did not have 3.3v output
    [dreamIO_board.kicad_pcb, dreamIO_board.sch]
2016-06-21 not sure what I did. have really messed up on keeping track of changes. I will do better by making branches! I think mostly what happened is there were some edits to the PCB which still needs to be r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
2016-07-14 removed ID base endpoint since mDNS now works and each board has a hostname through which to send OSC messages. Edited the Maxpatch example to reflect the change in API
2016-07-16 added animation effects for OTA updates and wifi connection. it would be a good idea in the future to add an animation wrapper for the neopixels. these animations are likely to get recycled and havin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
2016-07-16 added measurement of voltage divider, scaled to the minimum and maximum values of the battery, 2.6 and 4.2 respectively.
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2016-07-16 added the gerber and drill files for the working PCB. The current ki-cad files are mangled from some fixes that never happened.
    [dreamIO_board-B.Cu.gbr, dreamIO_board-B.Mask.gbr, dreamIO_board-B.SilkS.gbr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]
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2016-07-17 added an OSC out that tells what side teh cube is currently on, /side
2016-07-21 adjusted dreamIO.maxpat to have an OSC-route object with the deviceID before routing the regular endpints
2016-07-21 got record script to send update time to dreamIO through OSC via command line. This will be useful for setting dreamIO recording at different rates (and with the LEDs)
2016-07-21 added computers time to CSV output to track the beginning and end of time running. Can help find if internal clock of board is drifting.
2016-07-21 changed comment in ESP8266_OSCExample.ino while trying to understand why the voltage reading is going above 1 for /batt
2016-07-31 added a bunch of files that should have been there all along
    [dreamIO_board-B.Cu.gbr, dreamIO_board-B.Mask.gbr, dreamIO_board-B.SilkS.gbr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]
2016-07-31 fixed some issues with files in the git
    [dreamIO_BOM.csv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]
2016-07-31 fixed more file issues
    [dreamIO_firmware.ino]
2016-09-14 fixed master so the data stream can be recorded. This master is now stable
    [dreamIO_firmware.ino]
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
